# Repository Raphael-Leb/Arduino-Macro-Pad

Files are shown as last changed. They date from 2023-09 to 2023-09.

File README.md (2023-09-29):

# Arduino Macro Pad
 A small macropad programmed using arduino featuring programmable key sets, a knob and an oled screed

## Features
- Xiao rp2040 microcontroller
- Cherry mx keys
- An oled screen displaying the shortcuts set
- A clickable rotary encoder knob

  



## Design
### PCB
The pcb was made using kicad, the design files are in Mainpad/PCBfiles.
 *The keys are not organised properly, they need to be rearanged to match with the schematic. The keys are also not spaced enough for regular keycaps*
The gerber files are in Mainpad/ProdFiles, these should be all you need to produce more copies if you are unexperienced with pcb software



### Software
The entire software is made with arduino, the firmware_2040.ino contains the logic and the pins.h contains the configuration for configuring layout as well as shortcuts.
I tried to make this with a xiao esp32c3, but couldn't get the bluetooth keyboard and bluetooth mouse library working at simultanuously, so let me know if you find a fix. For now this will only work as a wired keypad.
*I will be making a frontend for configuring the pins.h in the near future.*

### Casing
The casing was made in solidworks with several models I found on grabcad. 
I had to make custom keycaps because the keys were too close together to fit standard caps, I followed the footprint's spacing but should've double checked if it was correct.
I first modeled a casing with the pcb tilted upward to fit the angle of my keyboard, but then decided on making it flat instead. The files are still there if that's what you prefer, but they are incomplete.
Initialy tried to make a press fit casing, but spacing proved to be quite a pain to nail down considering how 3d printed plastic warps. I used 6 m3 screws to secure everything.


### Parts
| Part | Link | Amount |
| --- | --- | --- |
| Cherry switch  | https://www.digikey.ca/en/products/detail/cherry-americas-llc/MX1A-E1NW/20180 | 8 |
| Rotary encoder | https://www.digikey.ca/en/products/detail/bourns-inc/PEC11R-4215K-S0024/4499662 | 1 |
| Diodes | https://www.digikey.ca/en/products/detail/smc-diode-solutions/1N4148/6022448 | 8 |
| rp2040 | https://www.digikey.ca/en/products/detail/seeed-technology-co-ltd/102010428/14672129 | 1 |
| screen | https://www.amazon.ca/GeeekPi-SSD1306-Display-Arduino-Raspberry/dp/B0833PF7ML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 | 1 |

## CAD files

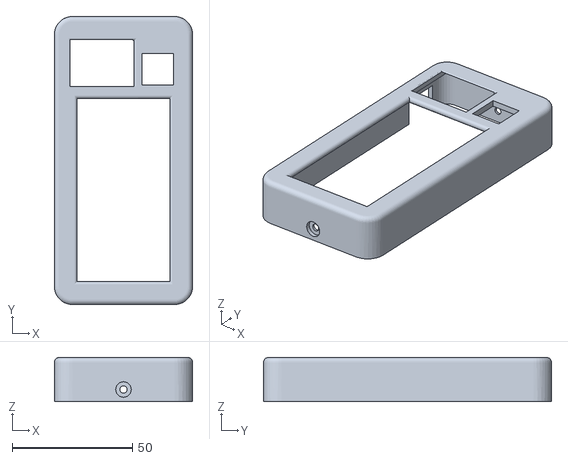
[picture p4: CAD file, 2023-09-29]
MainPad/stls/Knob^Assem1flatSLDASM - Top-1.STL
57.6 x 119.9 x 18.3

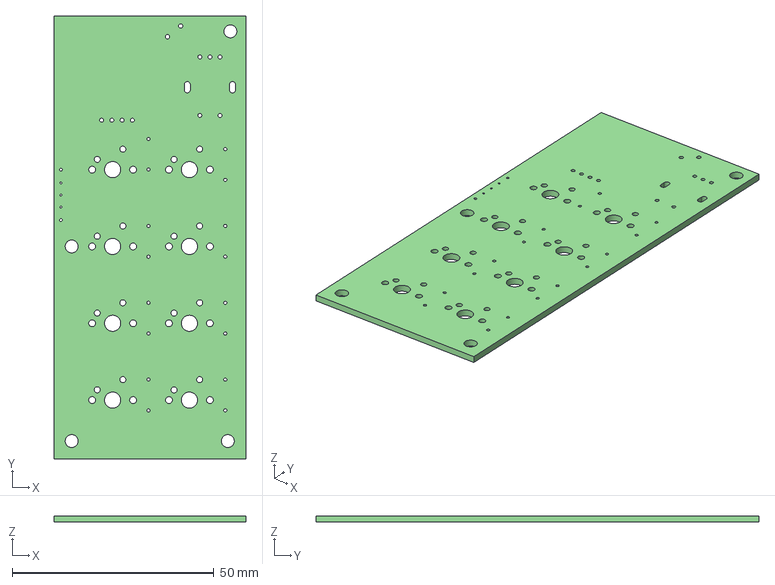
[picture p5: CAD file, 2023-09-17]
MainPad/Models/MainPad.step
47.5 x 109.9 x 1.60 mm

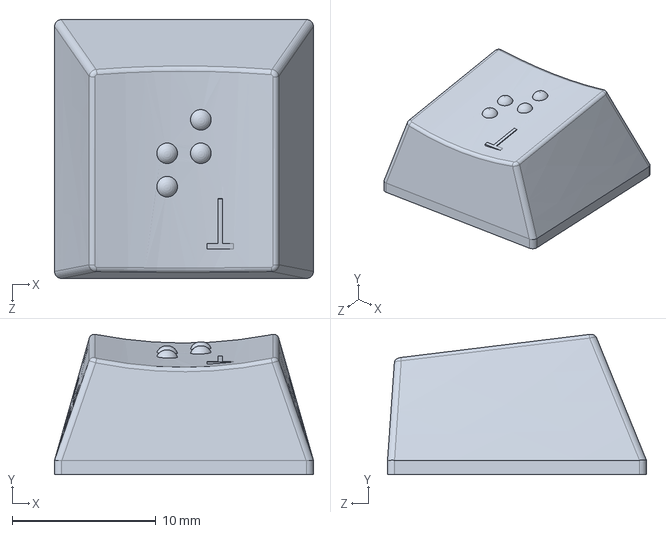
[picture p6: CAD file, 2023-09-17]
MainPad/Models/braille-key-caps-cherry-mx-compatible-rev-a-2-1.snapshot.7/BD99-001-0000020 - BRAILLE CAP - T - NRL 20211114.SLDPRT
18.0 x 9.76 x 18.0 mm

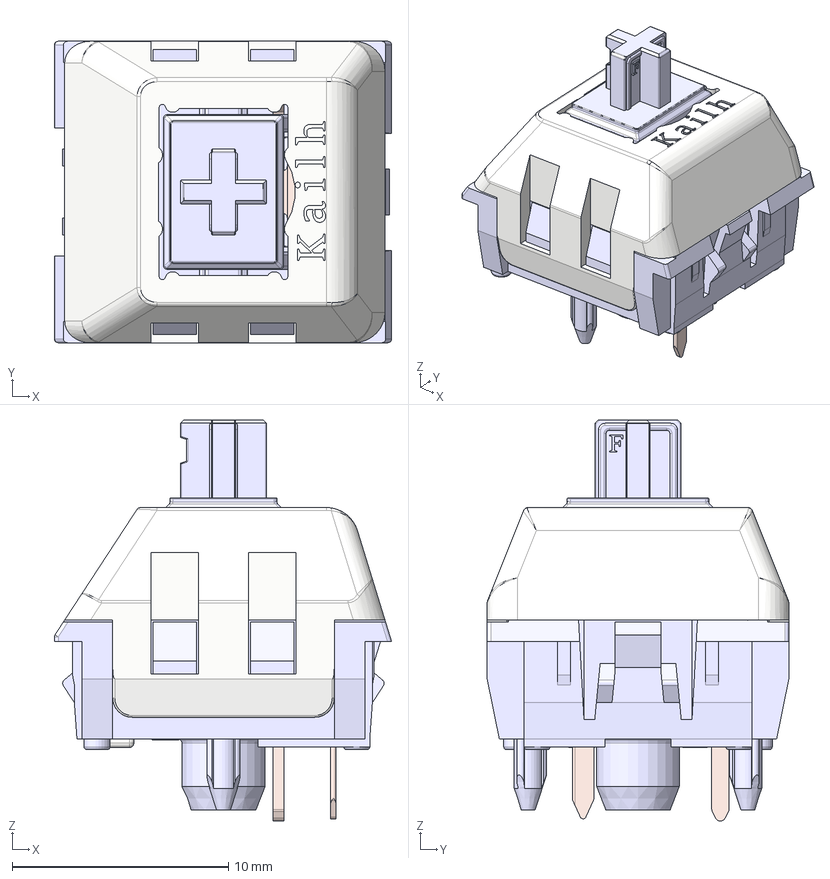
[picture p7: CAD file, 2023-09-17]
MainPad/Models/kailh-polia-switch-cherry-mx-compatible-1.snapshot.1/Kailh Polia.step
15.6 x 14.0 x 18.5 mm
Housing
ThickContact
SpringContact
Stem
Lid

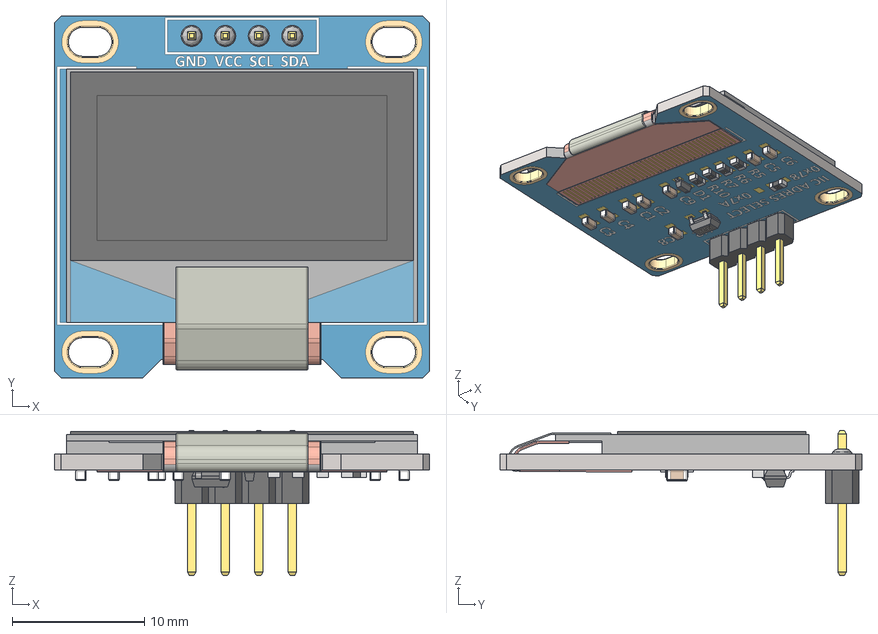
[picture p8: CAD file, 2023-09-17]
MainPad/Models/pantalla-oled-0-96-128x64-1.snapshot.7/Pantalla OLED 0.96'' 128x64.stp
28.4 x 27.4 x 11.0 mm
SOT-23_TOR
RES_CR16_MTK_1 x 4
RES_CR16_MTK
SOD323F_DIO

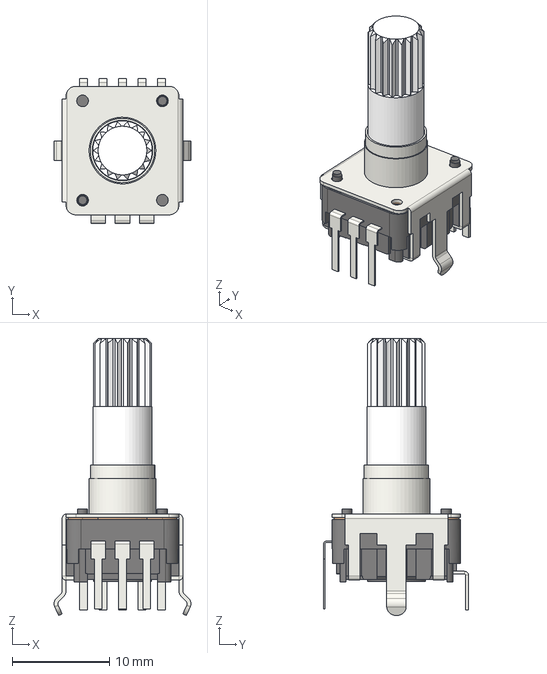
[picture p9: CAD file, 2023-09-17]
MainPad/Models/pel12t-encoder-rotativo-com-led-rgb-1.snapshot.1/PEL12T-4225S-S1024.step
14.1 x 14.9 x 28.4 mm

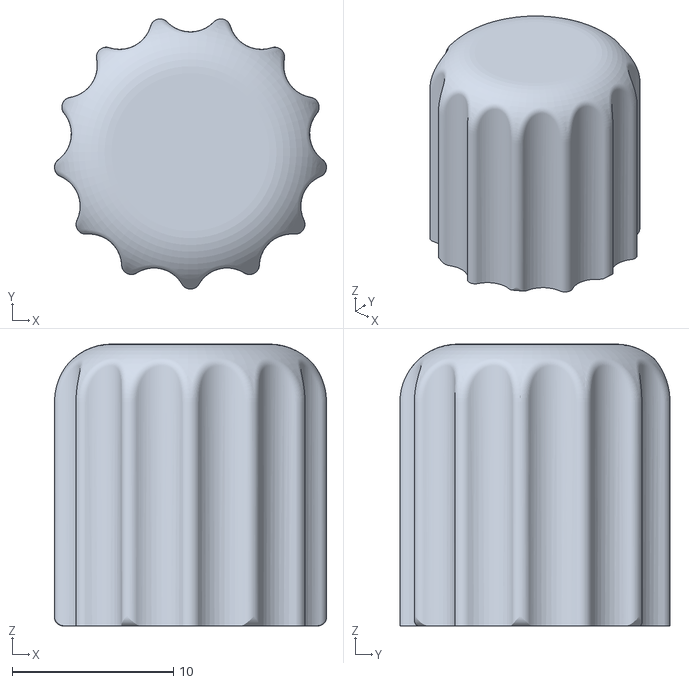
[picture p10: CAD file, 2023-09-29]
MainPad/stls/Knob.STL
16.9 x 16.8 x 17.5

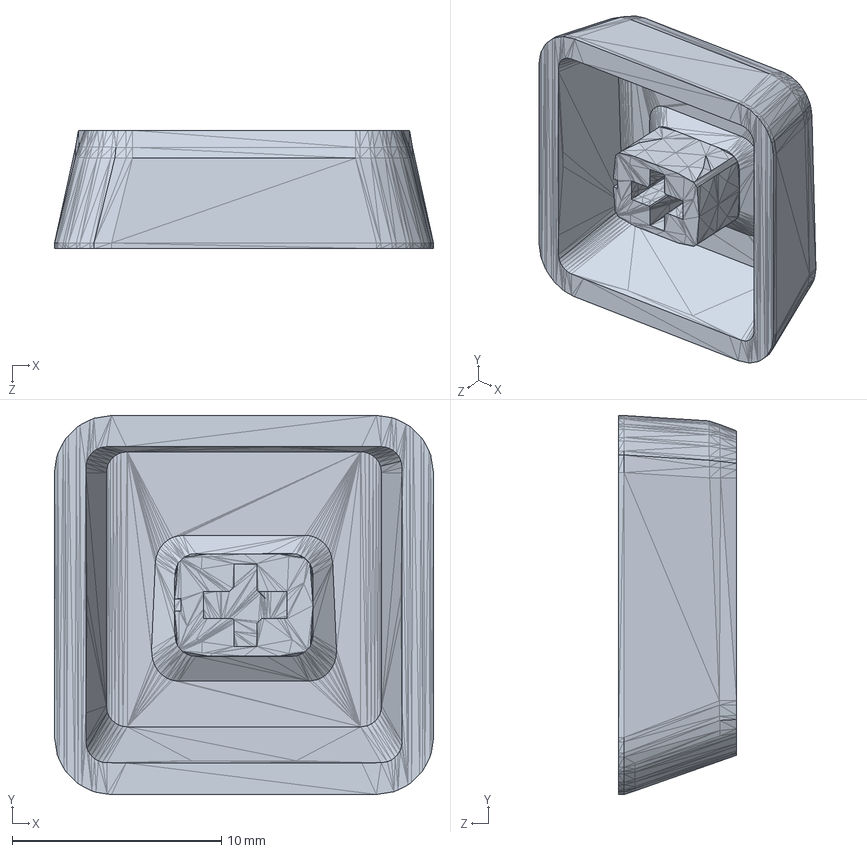
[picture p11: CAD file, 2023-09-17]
MainPad/Models/keycap_1u2.SLDPRT
18.1 x 18.1 x 5.66 mm

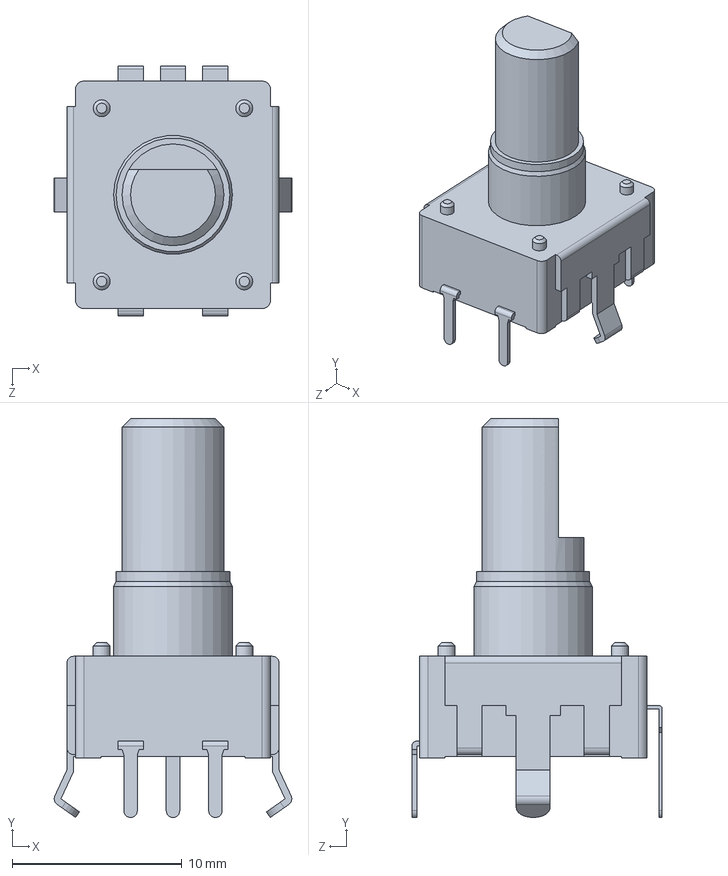
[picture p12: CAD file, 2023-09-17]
MainPad/Models/pec12r-4025f-s0024.SLDPRT
14.0 x 23.5 x 14.8 mm

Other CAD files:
MainPad/Models/Copy of Part7^Assem1flatSLDASM.SLDPRT
MainPad/Models/braille-key-caps-cherry-mx-compatible-rev-a-2-1.snapshot.7/STL's/BD99-001-0000012 - BRAILLE CAP - L - NRL 20211114.STL
MainPad/Models/Top.SLDPRT
MainPad/Models/braille-key-caps-cherry-mx-compatible-rev-a-2-1.snapshot.7/BD99-001-0000003 - BRAILLE CAP - C - NRL 20211114.SLDPRT
MainPad/Models/braille-key-caps-cherry-mx-compatible-rev-a-2-1.snapshot.7/STL's/BD99-001-0000025 - BRAILLE CAP - Y - NRL 20211114.STL
MainPad/Models/braille-key-caps-cherry-mx-compatible-rev-a-2-1.snapshot.7/BD99-001-0000004 - BRAILLE CAP - D - NRL 20211114.SLDPRT
MainPad/Models/braille-key-caps-cherry-mx-compatible-rev-a-2-1.snapshot.7/STL's/BD99-001-0000026 - BRAILLE CAP - Z - NRL 20211114.STL
MainPad/stls/Bottom.SLDPRT
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

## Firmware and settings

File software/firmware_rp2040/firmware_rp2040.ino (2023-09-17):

#include "Keyboard.h"
#include "Mouse.h"
#include "pins.h"
#include <Wire.h>
#include <Adafruit_GFX.h>
#include <Adafruit_SSD1306.h>

#define SCREEN_WIDTH 128 // OLED display width, in pixels
#define SCREEN_HEIGHT 64 // OLED display height, in pixels

Adafruit_SSD1306 display(SCREEN_WIDTH, SCREEN_HEIGHT, &Wire, -1);

volatile int lastEncoded = 0;
volatile long encoderValue = 0;

int activeKeybindSet = 0;
bool buttonPressed = false; // Variable to track button press state

void setup() {
  // Set up the serial monitor
  Serial.begin(9600);

  Mouse.begin();
  Keyboard.begin();

  // Set up the row pins as inputs with pull-up resistors
  for (int i = 0; i < NUM_ROWS; i++) {
    pinMode(ROW_PINS[i], INPUT_PULLUP);
  }
  // Set up the column pins as outputs
  for (int i = 0; i < NUM_COLS; i++) {
    pinMode(COL_PINS[i], OUTPUT);
  }

  pinMode(ROT_A, INPUT_PULLUP);
  pinMode(ROT_B, INPUT_PULLUP);
  pinMode(ROT_CLK, INPUT_PULLUP);

  Wire.begin();

  // Initialize the SSD1306 display
  if (!display.begin(SSD1306_SWITCHCAPVCC, 0x3C)) {
    Serial.println(F("SSD1306 initialization failed"));
    while (1); // Stop here if the display couldn't be initialized
  }

  attachInterrupt(digitalPinToInterrupt(ROT_A), updateEncoder, CHANGE);
  attachInterrupt(digitalPinToInterrupt(ROT_B), updateEncoder, CHANGE);
  
  displayKeybinds();
}

void loop() {
  // change keybind set
  if (digitalRead(ROT_CLK) == LOW) {
    activeKeybindSet++;
    if (activeKeybindSet >= NUM_KEYBIND_SETS) {
      activeKeybindSet = 0;
    }
    displayKeybinds(); // Update the display with the new keybind set
    delay(200); // debounce
  }

  // Scan each column for button presses
  for (int col = 0; col < NUM_COLS; col++) {
    digitalWrite(COL_PINS[col], LOW);
    for (int row = 0; row < NUM_ROWS; row++) {
      if (digitalRead(ROW_PINS[row]) == LOW) {
        // Button is pressed
        if (!buttonPressed) {
          buttonPressed = true; // Set button press state to true
          Serial.print("Row ");
          Serial.print(row);
          Serial.print(" Col ");
          Serial.print(col);
          Serial.println(" pressed");
          executeShortcut(row, col);
          delay(200);
        }
      }
      else {
        if (buttonPressed) {
          buttonPressed = false; // Reset button press state
          Serial.println("Button released");
          // Release all keys when button is released
          Keyboard.releaseAll();
        }
      }
      delay(10); // Delay to debounce the button
    }
    digitalWrite(COL_PINS[col], HIGH);
  }

  updateEncoder();
}

void executeShortcut(int row, int col) {
  const char* shortcutName = keybinds[activeKeybindSet][row][col];
  for (int i = 0; i < NUM_SHORTCUTS; i++) {
    if (strcmp(shortcutNames[i], shortcutName) == 0) {
      const char* shortcutCombo = shortcutCombos[i];
      int comboLength = 3; // Length of shortcutCombo, modify when adding longer shortcuts
      for (int j = 0; j < comboLength; j++) {
        Keyboard.press(shortcutCombo[j]);
        delay(10);
      }
    }
  }
}

void displayKeybinds(){
  display.clearDisplay(); // Clear the display
  display.setRotation(2);
  display.setTextSize(1.5); // Set text size
  display.setTextColor(SSD1306_WHITE); // Set text color
  display.drawRect(2, 2, 126, 62, SSD1306_WHITE);
  int cursorx = 5, cursory = 5;
  display.setCursor(cursorx, cursory); // Set cursor position

  // this it how this should work if i hadn't done the wiring while high off my ass 
  /*for (int col = 0; col < NUM_COLS; col++){
    for (int row = 0; row < NUM_ROWS; row++){
      display.setCursor(cursorx, cursory);
      display.print(keybinds[row][col]);
      cursory += 10;
    }
    cursorx = 50;
    cursory = 5;
  }*/

  for (int row = 0; row < NUM_ROWS; row++){
      display.setCursor(cursorx, cursory);
      display.print(keybinds[activeKeybindSet][row][1]);
      cursorx += 60;
      if (row==1){
        cursorx = 5;
        cursory += 15;
      }
  }
  cursorx = 5;
  cursory = 35;
  for (int row = 0; row < NUM_ROWS; row++){
    display.setCursor(cursorx, cursory);
    display.print(keybinds[activeKeybindSet][row][0]);
    cursorx += 60;
    if (row==1){
      cursorx = 5;
      cursory += 15;
    }
  }

  display.display();
}

void updateEncoder() {
  int MSB = digitalRead(ROT_A); // Most significant bit
  int LSB = digitalRead(ROT_B); // Least significant bit

  int encoded = (MSB << 1) | LSB;
  int sum = (lastEncoded << 2) | encoded;

  if (sum == 0b1101 || sum == 0b0100 || sum == 0b0010 || sum == 0b1011) {
    encoderValue++;
    // Clockwise rotation
    Mouse.move(0, 0, -1); // Scroll up
    Serial.println("Scrolling up");
  } else if (sum == 0b1110 || sum == 0b0111 || sum == 0b0001 || sum == 0b1000) {
    encoderValue--;
    // Counterclockwise rotation
    Mouse.move(0, 0, 1); // Scroll down
    Serial.println("Scrolling down");
  }

  lastEncoded = encoded;
}

////////////////////

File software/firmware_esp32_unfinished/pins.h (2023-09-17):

// Configuration Section

// Define the pins for the rows and columns
const int ROW_PINS[] = {D0, D1, D2, D3};
const int COL_PINS[] = {D8, D7};
const int NUM_ROWS = sizeof(ROW_PINS) / sizeof(ROW_PINS[0]);
const int NUM_COLS = sizeof(COL_PINS) / sizeof(COL_PINS[0]);

// Define pins for the rotary encoder(s)
const int ROT_A = D10;
const int ROT_B = D9;
const int ROT_CLK = D6;

// Define the shortcuts
const int NUM_SHORTCUTS = 3;
const char* shortcutNames[] = {"undo", "copy", "paste"};
const char shortcutCombos[NUM_SHORTCUTS][2] = {
  {KEY_LEFT_CTRL, 'z'},
  {KEY_LEFT_CTRL, 'c'},
  {KEY_LEFT_CTRL, 'v'}
};

// Define the keybinds
const char* keybinds[NUM_ROWS][NUM_COLS] = {
  {"undo", "undo"},
  {"copy", "paste"},
  {"copy", "paste"},
  {"copy", "paste"}
};

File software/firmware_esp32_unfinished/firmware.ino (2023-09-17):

#include <BleKeyboard.h>
//#include <BleMouse.h>
#include "pins.h"

BleKeyboard bleKeyboard;
//BleMouse bleMouse;

int lastState = 0;
int currentState = 0;

void setup() {
  // Set up the serial monitor
  Serial.begin(9600);

  bleKeyboard.begin();
  //bleMouse.begin();
  // Set up the row pins as inputs with pull-up resistors
  for (int i = 0; i < NUM_ROWS; i++) {
    pinMode(ROW_PINS[i], INPUT_PULLUP);
  }
  // Set up the column pins as outputs
  for (int i = 0; i < NUM_COLS; i++) {
    pinMode(COL_PINS[i], OUTPUT);
  }

  pinMode(ROT_A, INPUT_PULLUP);
  pinMode(ROT_B, INPUT_PULLUP);

}

void loop() {
  // Read the current state of the rotary encoder
  currentState = digitalRead(ROT_A);

  // Scan each column for button presses
  for (int col = 0; col < NUM_COLS; col++) {
    digitalWrite(COL_PINS[col], LOW);
    for (int row = 0; row < NUM_ROWS; row++) {
      if (digitalRead(ROW_PINS[row]) == LOW) {
        // Button is pressed
        Serial.print("Button ");
        Serial.print(row * NUM_COLS + col);
        Serial.println(" pressed");

        executeShortcut(row, col);

        delay(200); // debounce
      }
      else {
        Serial.println("nothing");
      }
    }
    digitalWrite(COL_PINS[col], HIGH);
  }
    // Check if there's a change in the state of the rotary encoder
  /*if (currentState != lastState) {
    if (digitalRead(ROT_B) != currentState) {
      // Clockwise rotation
      bleMouse.move(0, 0, 1); // Scroll up
      Serial.println("scrolling up");
    } else {
      // Counterclockwise rotation
      bleMouse.move(0, 0, -1); // Scroll down
      Serial.println("scrolling down");
    }
    delay(100); // Delay to debounce the rotary encoder
  }

  lastState = currentState;*/

}

void executeShortcut(int row, int col) {
  const char* shortcutName = keybinds[row][col];
  for (int i = 0; i < NUM_SHORTCUTS; i++) {
    if (strcmp(shortcutNames[i], shortcutName) == 0) {
      const char* shortcutCombo = shortcutCombos[i];
      int comboLength = sizeof(shortcutCombo) / sizeof(shortcutCombo[0]);
      for (int j = 0; j < comboLength; j++) {
        bleKeyboard.press(shortcutCombo[j]);
      }
      delay(200);
      bleKeyboard.releaseAll();
    }
  }
}

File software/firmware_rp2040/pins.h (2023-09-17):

// Configuration Section

// Define the pins for the rows and columns
const int ROW_PINS[] = {D0, D1, D2, D3};
const int COL_PINS[] = {D8, D7};
const int NUM_ROWS = sizeof(ROW_PINS) / sizeof(ROW_PINS[0]);
const int NUM_COLS = sizeof(COL_PINS) / sizeof(COL_PINS[0]);

// Define pins for the rotary encoder(s)
const int ROT_A = D10;
const int ROT_B = D9;
const int ROT_CLK = D6;

// Define the shortcuts
const int NUM_SHORTCUTS = 28;
const char* shortcutNames[] = {"undo", "copy", "paste", "view", "pipette", "ui tog", "redo", "snap left", "snap right", "search", "task view", 
                                "lasso", "steady", "fill", "fit view", "brushes", "move", "thick +", "thick -", "command", "comment","uncomment",
                                "save","split", "view face", "view all", "fullscreen", "minimize"};
const char shortcutCombos[NUM_SHORTCUTS][3] = {
  {KEY_LEFT_CTRL, 'z'},
  {KEY_LEFT_CTRL, 'c'},
  {KEY_LEFT_CTRL, 'v'},
  {KEY_LEFT_CTRL, '8'},
  {KEY_LEFT_ALT, 'i'},
  {'t'},
  {KEY_LEFT_CTRL, 'y'},
  {KEY_LEFT_GUI, KEY_LEFT_ARROW},
  {KEY_LEFT_GUI, KEY_RIGHT_ARROW},
  {KEY_LEFT_GUI, '1'},
  {KEY_LEFT_GUI, KEY_TAB},
  {'l'},
  {KEY_LEFT_CTRL, 'r'},
  {KEY_LEFT_CTRL, 'f'},
  {KEY_LEFT_CTRL, '0'},
  {KEY_LEFT_CTRL, 'b'},
  {' '},
  {KEY_LEFT_CTRL, KEY_LEFT_ALT, 'k'},
  {KEY_LEFT_CTRL, KEY_LEFT_ALT, 'l'},
  {KEY_LEFT_CTRL, KEY_LEFT_SHIFT, 'p'},
  {KEY_LEFT_CTRL, KEY_LEFT_ALT, 'k'},
  {KEY_LEFT_CTRL, KEY_LEFT_ALT, 'l'},
  {KEY_LEFT_CTRL, 's'},
  {KEY_LEFT_CTRL, KEY_LEFT_ALT, 'q'},
  {KEY_LEFT_CTRL, '8'},
  {KEY_LEFT_CTRL, '7'},
  {KEY_F11},
	{KEY_LEFT_GUI, 'm'}
};

const int NUM_KEYBIND_SETS = 4; // Change the value according to your requirements

// Define the keybinds
const char* keybinds[NUM_KEYBIND_SETS][NUM_ROWS][NUM_COLS] = {
  {{"undo", "snap left"},
   {"redo", "snap right"},
   {"fullscreen", "search"},
   {"minimize", "task view"}},
  
  {{"undo", "steady"},
   {"redo", "fit view"},
   {"ui tog", "brushes"},
   {"thick -", "thick +"}},
  
  {{"comment", "command"},
   {"uncomment", "undo"},
   {"split", "snap left"},
   {"save", "snap right"}},

  {{"undo", "view all"},
   {"task view", "view face"},
   {"split", "snap left"},
   {"save", "snap right"}}
};

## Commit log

2023-09-17 Finished assembly
    [Bottom.SLDPRT, Top.SLDPRT, keycap_1u2.SLDPRT]
2023-09-29 removed useless stls
    [Top - Kailh Polia.step-1 Kailh Polia_1.step-1 Housing.step-1.STL, Top - Kailh Polia.step-1 Kailh Polia_1.step-1 Lid.step-1.STL, Top - Kailh Polia.step-1 Kailh 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]
